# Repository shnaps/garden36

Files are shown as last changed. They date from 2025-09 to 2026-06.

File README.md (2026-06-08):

# garden36 🌱

A 36-key wireless split keyboard with Kailh Choc hotswap switches, nice!nano v2 controllers, and nice!view displays.

<p align="center">
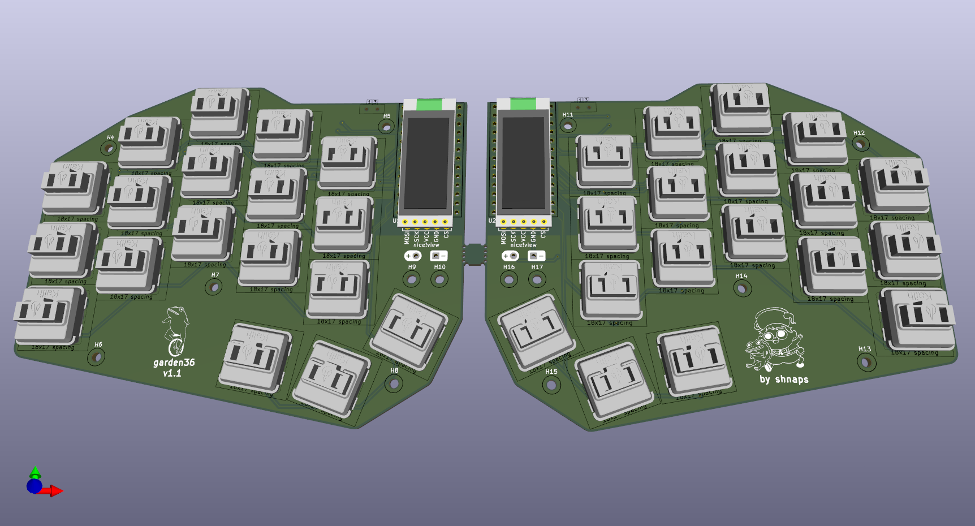
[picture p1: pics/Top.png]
garden36 top view
  
</p>

<p align="center">
  
  
  
  
</p>

---

## Features

- **36 keys** — 3×5 column-stagger + 3 thumb keys per half
- **Wireless** — nRF52840 via nice!nano v2, ZMK firmware
- **Hotswap** — Kailh Choc v1 sockets, swap switches without soldering
- **Display** — nice!view MIP display per half (WPM, layer, battery)
- **Battery** — JST-PH LiPo connector + power switch per half
- **Low profile** — Choc spacing, slim build

---

## Gallery

| Top | Bottom |
|-----|---|
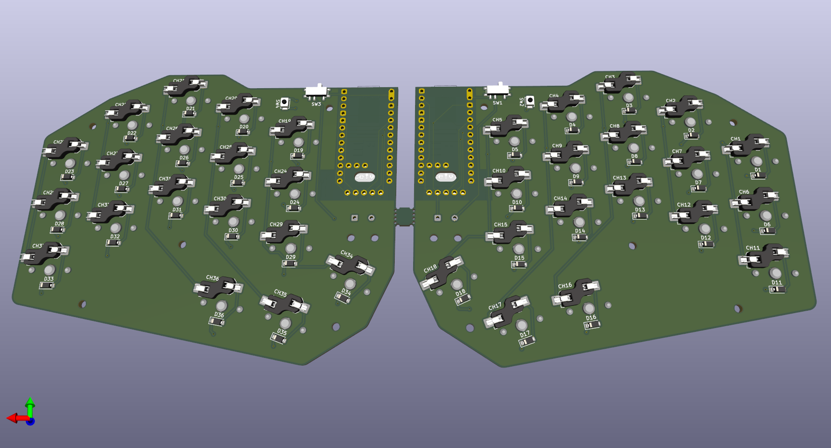
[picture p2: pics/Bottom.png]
bottom
| top |  |

> Photos of the built keyboard coming once V2 is assembled. See `pics/photos/` for updates.

---

## Bill of Materials

Full BOM with source links: [docs/bom.md](docs/bom.md)

| Component | Qty |
|---|-----|
| nice!nano v2 | 2 |
| nice!view | 2 |
| Kailh Choc v1 switch | 36 |
| Kailh hotswap socket CPG135001S30 | 36 |
| 1N4148W diode SOD-123 | 36 |
| MSK12C02-HB power switch | 2 |
| B3U-1000P reset button | 2 |
| JST S2B-PH-SM4-TB battery connector | 2 |
| LiPo battery ~110–300 mAh | 2 |
| M2 standoffs + screws | ~28 |
| Choc keycaps | 36 |

---

## PCB

Gerbers and drill files for JLCPCB/PCBWay are in the [latest release](https://github.com/shnaps/garden36/releases/latest).

DXF and SVG edge cuts for laser-cutting plates: [`exports/`](exports/)

---

## Build Guide

Step-by-step assembly instructions: [docs/buildguide.md](docs/buildguide.md)

---

## Firmware

ZMK config: [github.com/shnaps/zmk-config](https://github.com/shnaps/zmk-config)

Flash via UF2 — double-tap reset on each half to enter bootloader, drag-and-drop `.uf2`. See build guide for details.

---

## Case

A **parametric case generator** lives in [`case-gen/`](case-gen/) — it builds
the case (bottom tray, choc switch plate, controller cover) straight from
`garden36.kicad_pcb`, so it always fits the board. Print files in
`case-gen/out/`. See the [case-gen README](case-gen/README.md) for hardware,
parameters, and the in-progress controller-on-bottom redesign.

Older hand-built STEP files remain in [`case/`](case/).

---

## Design History

- **V1** — initial design, 5-column, wired (see [`v1` branch](https://github.com/shnaps/garden36/tree/v1))
- **V2** (current) — redesigned with wireless, nice!view displays, hotswap

---

## Credits

- [marbastlib](https://github.com/ebastler/marbastlib) by ebastler — Choc switch and controller footprints
- [nice!keyboards](https://nicekeyboards.com) — nice!nano and nice!view hardware
- Split keyboard inspiration: [MRIYA](https://github.com/themaxbang/MRIYA), [temper](https://github.com/raeedcho/temper), [urchin](https://github.com/duckyb/urchin)

---

## License

[MIT](LICENSE) © 2025 Viachaslau Ravinski

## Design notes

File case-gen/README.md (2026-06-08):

# garden36 — parametric case generator

Generates the 3D-printed case directly from `garden36.kicad_pcb`, so the case
always fits the board. Reads the board outline, switch positions (with splay),
mounting holes, and the controller / nice!view / power / reset / battery
locations, then builds each part as a STEP + STL.

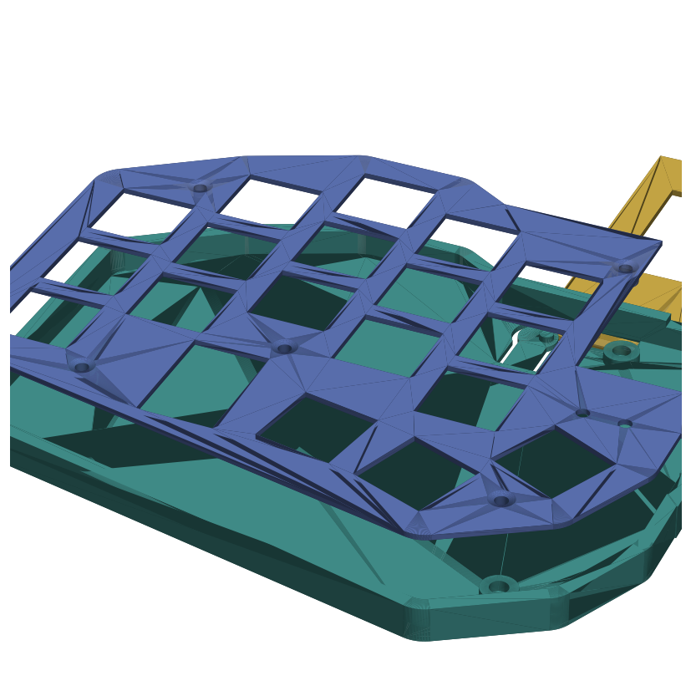
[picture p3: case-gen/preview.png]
exploded preview


> **Status: work in progress.** Geometry is print-tested and iterating. A
> larger redesign is planned — see *Next* below.

## Parts (per half)

| File | What |
|---|---|
| `*_bottom` | tray: floor, perimeter wall, 5 printed standoffs (insert pockets), printed reset flexure, power-switch slot, USB notch |
| `*_top` | choc switch plate (rotated cutouts follow key splay), logo windows, controller opening, screw bosses |
| `*_cover_view` | flat controller cover with nice!view window, floats on the 2 battery standoffs |
| `*_cover_plain` | same cover, solid (display removed) |

Outputs land in `out/stl/` (slicer) and `out/step/` (CAD).

## Hardware (per half)

| Use | Part |
|-----|---|
| 5 case columns | printed standoff + **M2×3×OD3.5 heat-set insert** + **M2×8 countersunk** from plate |
| Controller cover (display) | **M2×10** F-F standoff at each battery hole + **M2×4** screws |
| Controller cover (plain) | **M2×7** F-F standoff instead |

## Run

```bash
# one-time env (build123d needs Python <=3.12)
uv venv --python 3.12 .venv-case
uv pip install --python .venv-case build123d numpy-stl matplotlib

# generate
.venv-case/Scripts/python extract_pcb.py   # PCB -> pcb_data.json
.venv-case/Scripts/python case_gen.py       # -> out/stl, out/step
```

Edit a PCB feature in KiCad → rerun both → the case refits.

## Key parameters (`case_gen.py`)

All in mm, top of file. The ones that matter for fit:

- `UNDER_PCB` — space under the PCB (choc socket clearance + insert seat)
- `ABOVE_PCB` — plate underside above PCB = where the choc switches hold the
  plate. **Tune this to your exact top/bottom gap** (1.6mm plates sit ~1mm proud
  of the 1.2–1.3 clip notch)
- `PLATE_T` — 1.6 (held by screws). Drop to 1.3 if you want choc clips to engage
- `CTRL_STANDOFF` / `DISPLAY_TOP` — controller cover height; must clear the
  nice!view

## Next — controller-on-bottom redesign

Resoldering the nano to the **bottom** of the PCB (the footprints are fully
through-hole / reversible, so no board respin needed). This lets the nice!view
sit low on top instead of stacked on the nano → near-flush top, USB-C notch
moves to the bottom wall, battery moves under the PCB. Case will be regenerated
for that stack once the board is reworked.

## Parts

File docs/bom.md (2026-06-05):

# Bill of Materials — garden36

Per side × 2 = full build. Quantities below are **per keyboard** (both halves).

## Electronics

| Component | Qty | Notes | Source |
|---|-----|---|---|
| nice!nano v2 | 2 | nRF52840 wireless MCU, one per half | [typeractive](https://typeractive.xyz/products/nice-nano) |
| nice!view | 2 | MIP display, one per half | [typeractive](https://typeractive.xyz/products/nice-view) |
| Kailh Choc v1 switch | 36 | Any Choc v1 linear/tactile/clicky | [typeractive](https://typeractive.xyz/collections/switches) |
| Kailh Choc hotswap socket CPG135001S30 | 36 | | [typeractive](https://typeractive.xyz/products/kailh-hotswap-sockets) |
| 1N4148W diode SOD-123 | 36 | One per switch | [LCSC C2290336](https://www.lcsc.com/product-detail/C2290336.html) / AliExpress |
| MSK12C02-HB slide switch | 2 | Power on/off per half | [LCSC C431540](https://www.lcsc.com/product-detail/C431540.html) |
| B3U-1000P tactile reset switch | 2 | One per half | [LCSC C841584](https://www.lcsc.com/product-detail/C841584.html) |
| JST S2B-PH-SM4-TB battery connector | 2 | | [LCSC C295747](https://www.lcsc.com/product-detail/C295747.html) |
| LiPo battery 301230 or similar | 2 | ~100–300 mAh, fits under MCU | AliExpress |
| Mill-Max 315-43-112-41-003000 socket (12-pin) | 4 | For socketing nice!nano (optional but recommended) | [Digikey](https://www.digikey.com) |
| Mill-Max 315-43-105-41-003000 socket (5-pin) | 4 | For socketing nice!view (optional but recommended) | [Digikey](https://www.digikey.com) |

## PCB & Case

| Item | Qty | Notes |
|---|-----|---|
| garden36 PCB | 2 halves | Order via JLCPCB/PCBWay from gerbers in release |
| Top plate | 2 | `case/Only top.step` (FR4 or acrylic, 1.5mm) |
| Bottom plate | 2 | `case/Bottom left.step`, `case/Bottom right.step` |
| M2 × 6mm standoff | ~14 | Exact qty depends on case variant |
| M2 × 4mm screw | ~28 | |
| Choc keycaps | 36 | Low-profile Choc spacing | [typeractive](https://typeractive.xyz/collections/keycaps) |

## Optional

| Item | Notes |
|---|---|
| TRRS cable | If using wired split connection (ZMK supports wireless only, no TRRS needed) |
| USB-C cable | For flashing firmware |

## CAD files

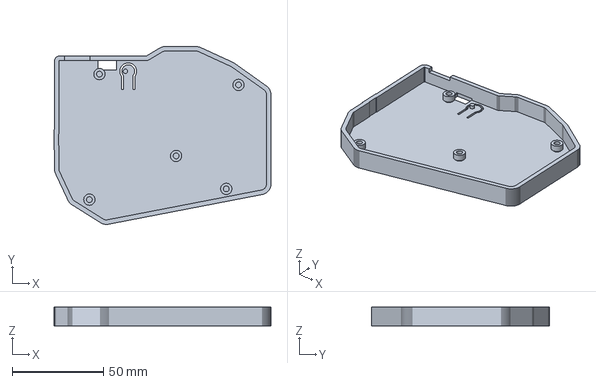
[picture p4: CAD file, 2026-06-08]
case-gen/out/step/right_bottom.step
118.8 x 97.4 x 10.4 mm

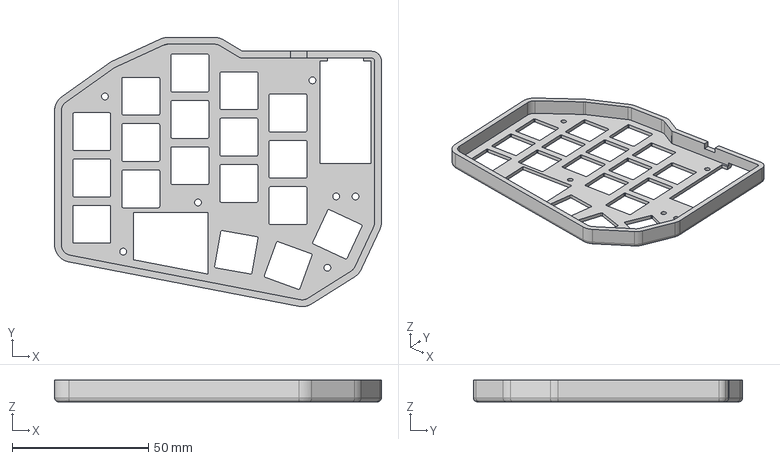
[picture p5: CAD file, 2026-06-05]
case/Untitled.step
120.0 x 98.8 x 8.00 mm

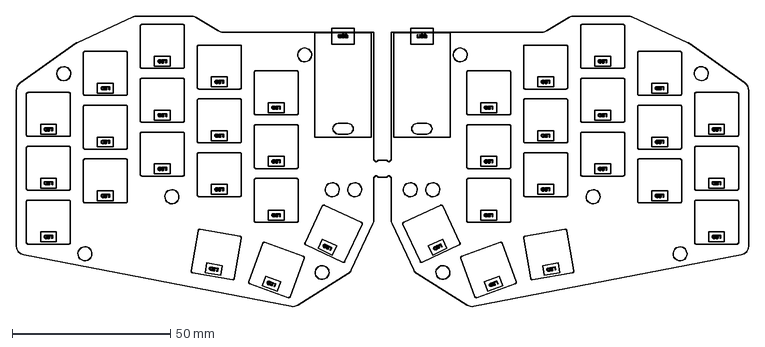
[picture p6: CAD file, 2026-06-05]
exports/garden36-Edge_Cuts.dxf
231.5 x 91.9 mm

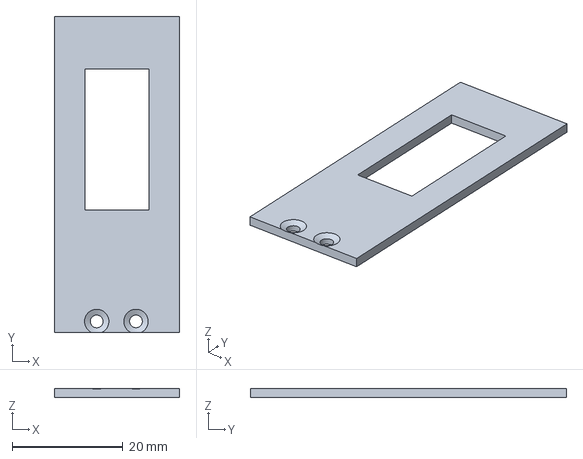
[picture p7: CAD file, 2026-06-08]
case-gen/out/step/right_cover_view.step
22.6 x 57.1 x 1.60 mm

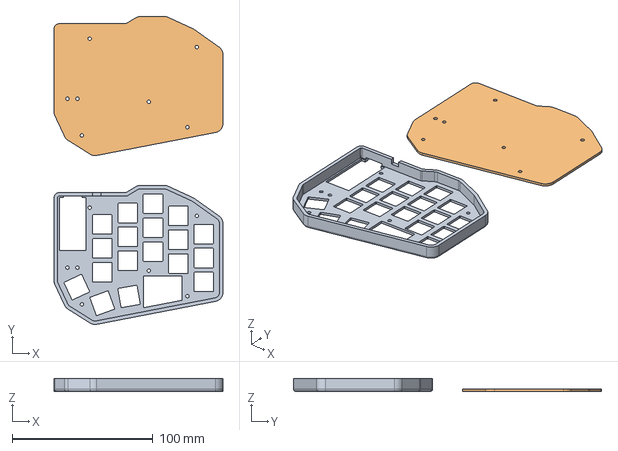
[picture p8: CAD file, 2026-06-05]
case/Left.step
120.0 x 218.8 x 9.00 mm

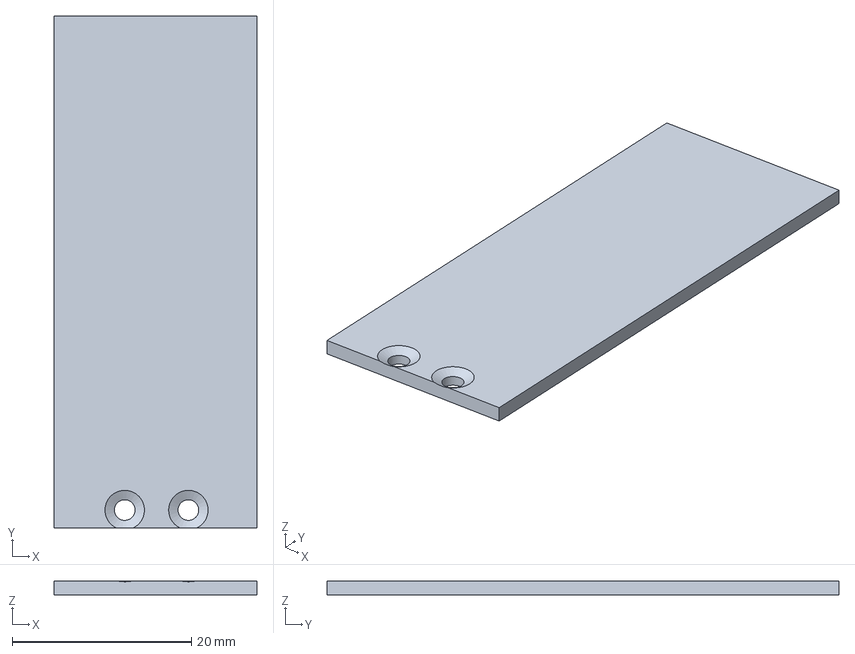
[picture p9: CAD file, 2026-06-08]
case-gen/out/step/left_cover_plain.step
22.6 x 57.1 x 1.60 mm

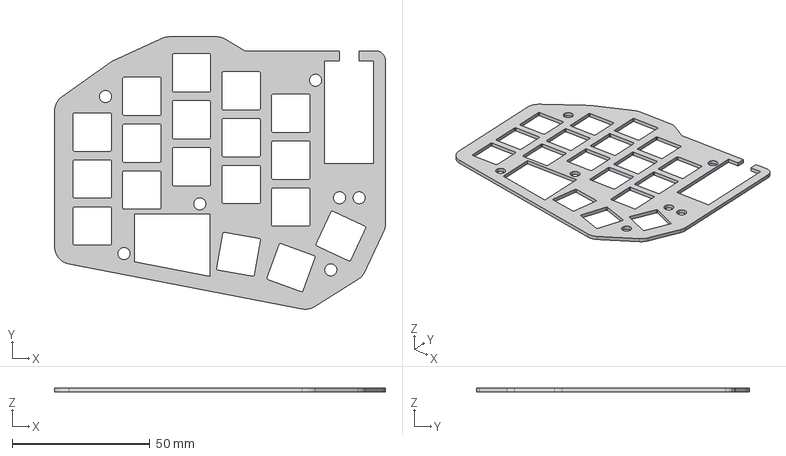
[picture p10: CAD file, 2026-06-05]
case/Only top.step
120.0 x 98.8 x 1.60 mm

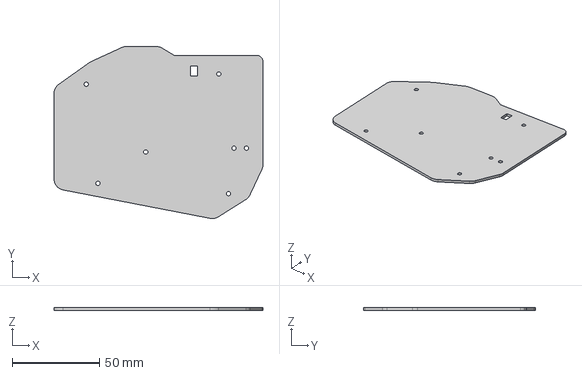
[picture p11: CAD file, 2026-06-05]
case/Bottom right.step
120.0 x 98.8 x 1.60 mm

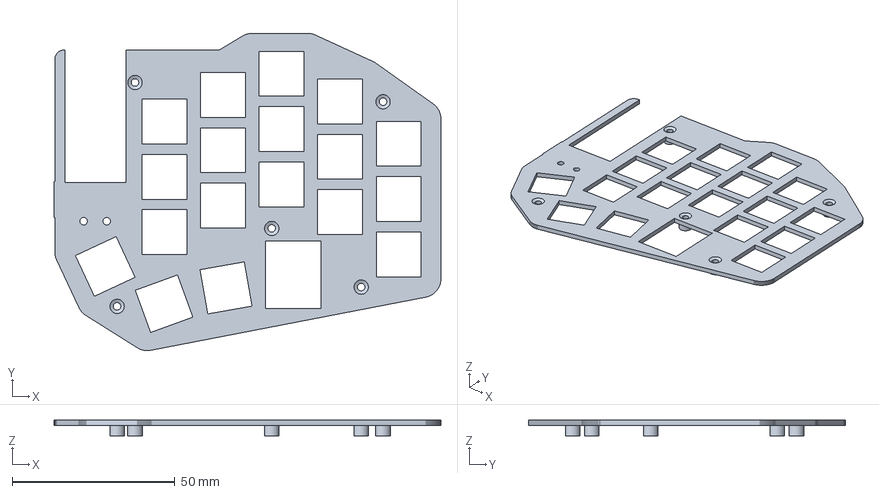
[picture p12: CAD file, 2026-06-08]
case-gen/out/step/right_top.step
118.8 x 97.4 x 4.80 mm

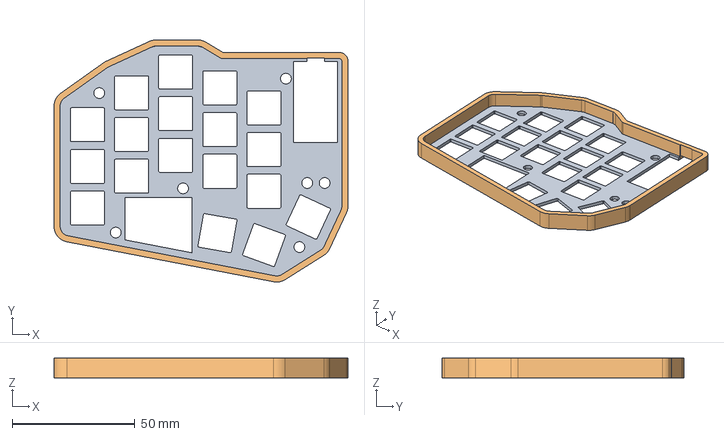
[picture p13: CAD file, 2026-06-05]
case/Rn.step
120.0 x 98.8 x 8.00 mm

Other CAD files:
case-gen/out/step/right_cover_plain.step
case/Bottom left.step
case-gen/out/step/left_top.step
case/Right.step
case-gen/out/step/left_cover_view.step
case-gen/out/step/left_bottom.step
case/Top2.step
case/drawing.FCStd
case-gen/out/stl/left_bottom.stl
case-gen/out/stl/left_cover_plain.stl
case-gen/out/stl/left_cover_view.stl
case-gen/out/stl/left_top.stl
case-gen/out/stl/right_bottom.stl
case-gen/out/stl/right_cover_plain.stl
case-gen/out/stl/right_cover_view.stl
case-gen/out/stl/right_top.stl

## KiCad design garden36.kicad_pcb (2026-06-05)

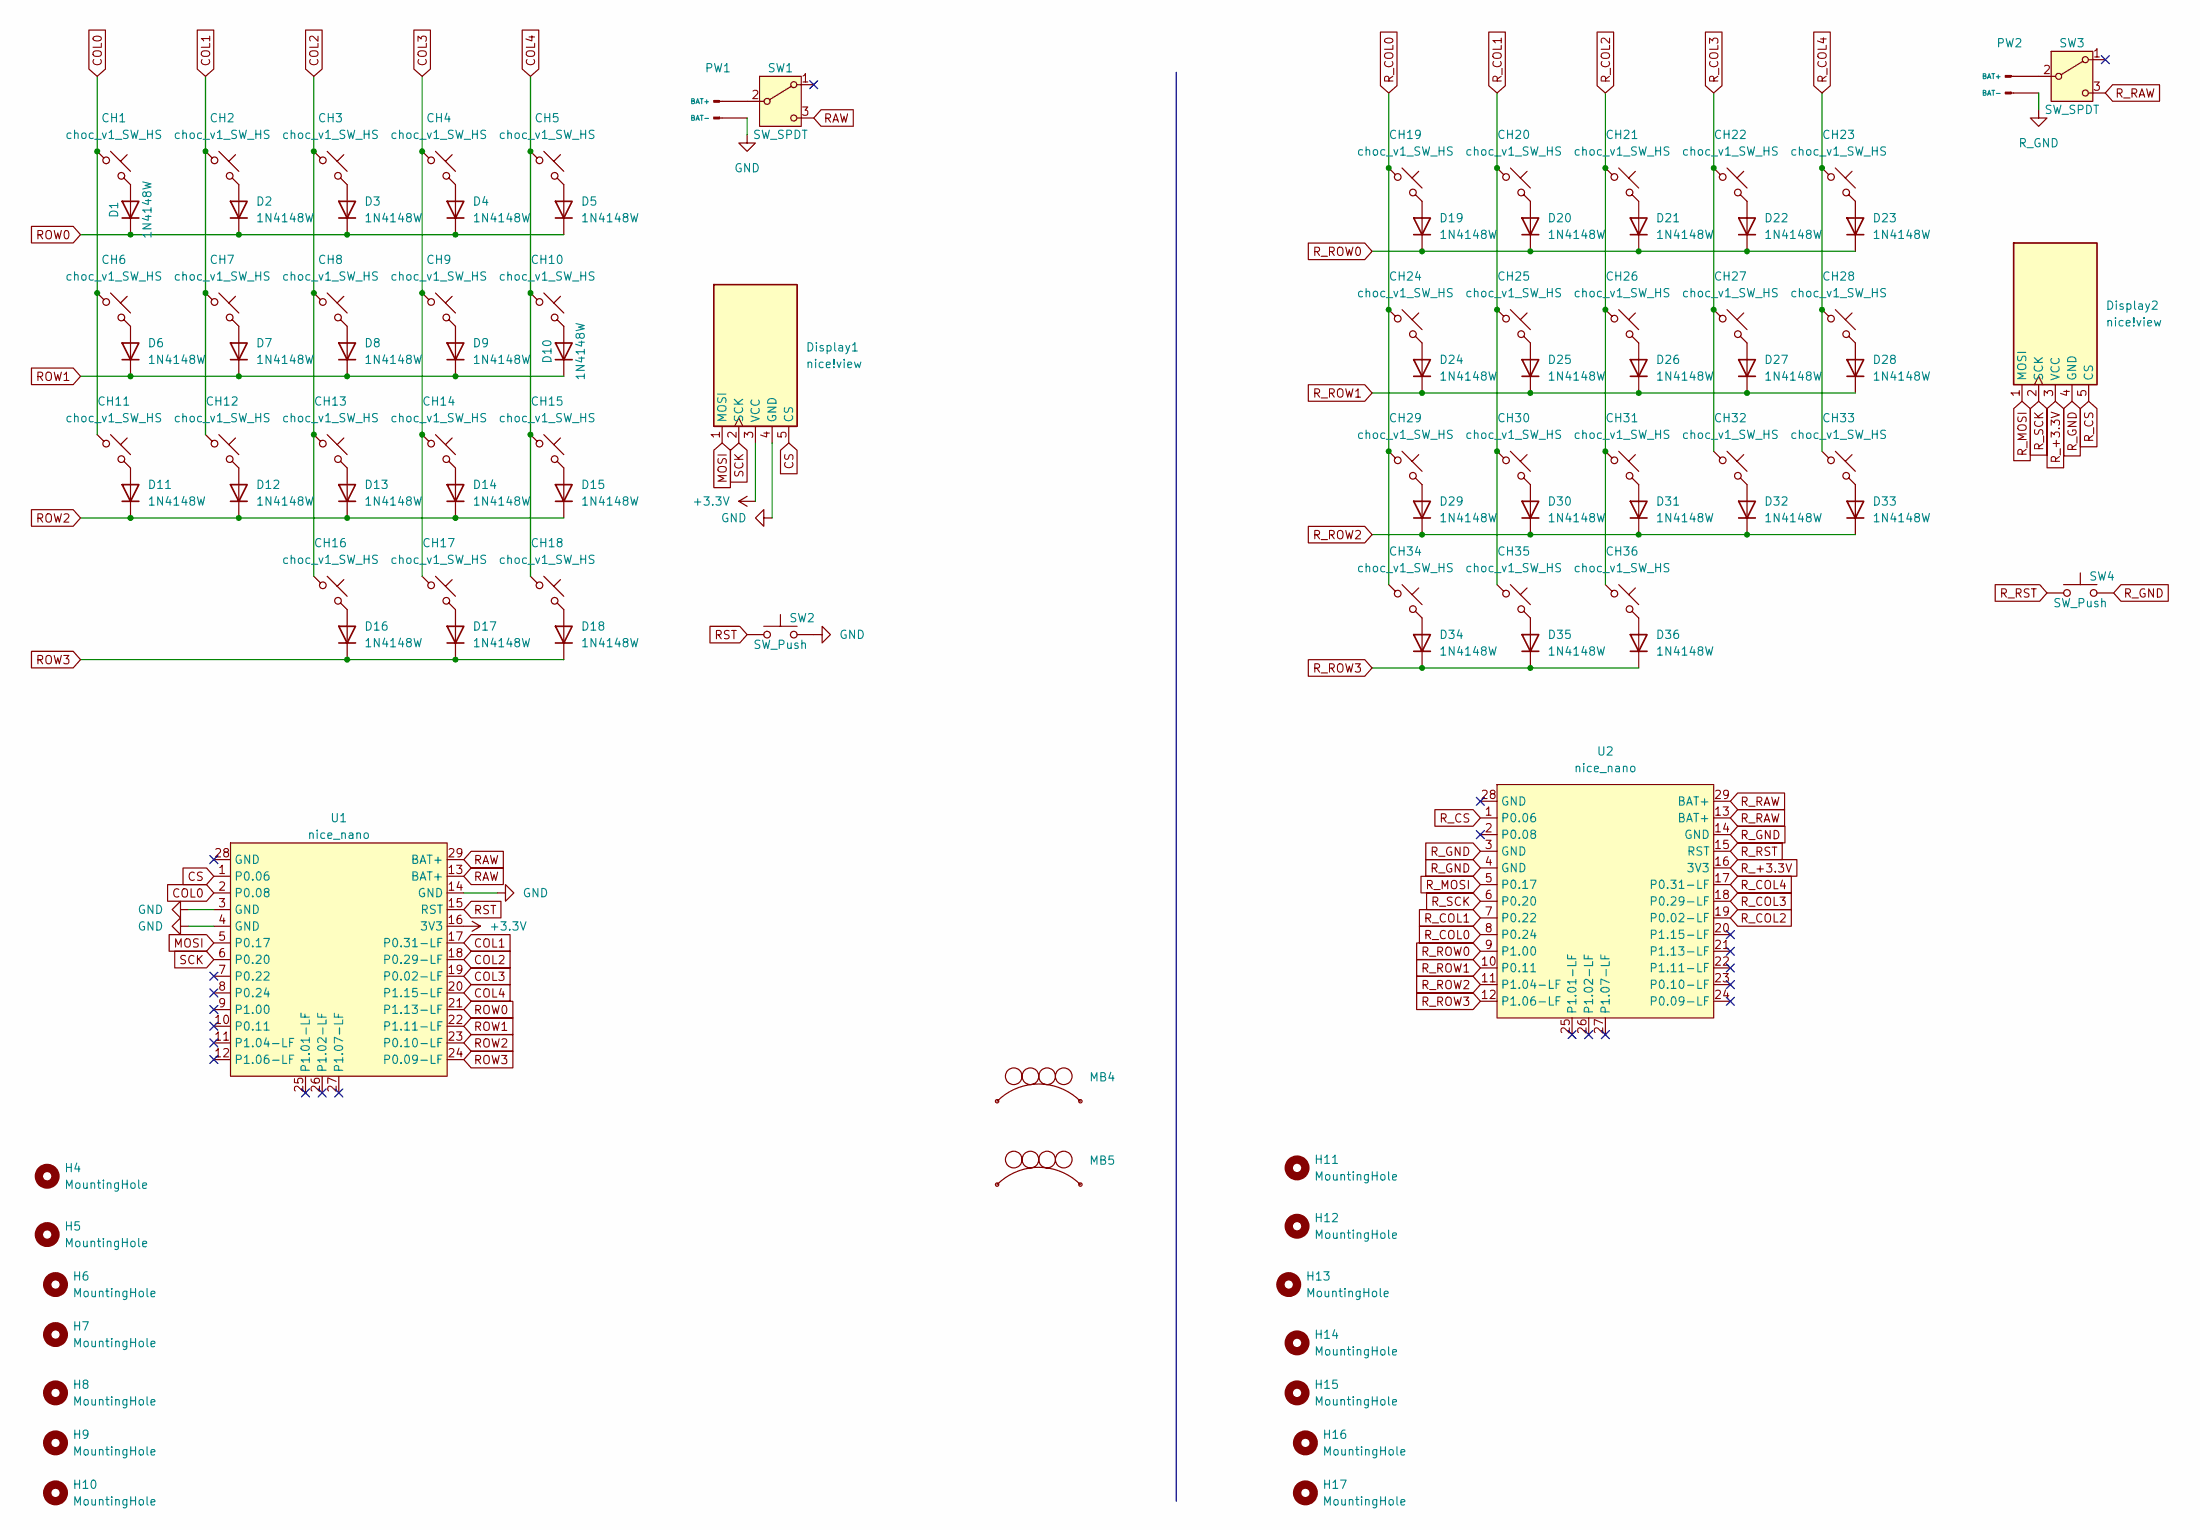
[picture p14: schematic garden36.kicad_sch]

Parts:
CH1, CH2, CH3, CH4, CH5, CH6, CH7, CH8, CH9, CH10, CH11, CH12, CH13, CH14, CH15, CH16, CH17, CH18, CH19, CH20, CH21, CH22, CH23, CH24, CH25, CH26, CH27, CH28, CH29, CH30, CH31, CH32, CH33, CH34, CH35, CH36: choc_v1_SW_HS; SW_choc_v1_HS_CPG135001S30_1u
D1, D2, D3, D4, D5, D6, D7, D8, D9, D10, D11, D12, D13, D14, D15, D16, D17, D18, D19, D20, D21, D22, D23, D24, D25, D26, D27, D28, D29, D30, D31, D32, D33, D34, D35, D36: 1N4148W; D_SOD-123
Display1, Display2: nice!view; nice_view
H4, H5, H6, H7, H8, H9, H10, H11, H12, H13, H14, H15, H16, H17: MountingHole; MountingHole_2.2mm_M2
MB4, MB5: mousebites_1mm
PW1, PW2: Battery
SW1, SW3: SW_SPDT; SW_MSK12C02-HB
SW2, SW4: SW_Push; SW_SPST_B3U-1000P
U1, U2: nice_nano; nice_nano_AH_USBdn

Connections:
+3.3V: Display1.3 (VCC), U1.16 (3V3)
COL0: CH1.1, CH6.1, CH11.1, U1.2 (P0.08)
COL1: CH2.1, CH7.1, CH12.1, U1.17 (P0.31-LF)
COL2: CH3.1, CH8.1, CH13.1, CH16.1, U1.18 (P0.29-LF)
COL3: CH4.1, CH9.1, CH14.1, CH17.1, U1.19 (P0.02-LF)
COL4: CH5.1, CH10.1, CH15.1, CH18.1, U1.20 (P1.15-LF)
CS: Display1.5 (CS), U1.1 (P0.06)
GND: Display1.4 (GND), PW1.2 (BAT-), SW2.2, U1.3 (GND), U1.4 (GND), U1.14 (GND)
MOSI: Display1.1 (MOSI), U1.5 (P0.17)
unnamed: CH1.2, D1.2 (A)
unnamed: CH2.2, D2.2 (A)
unnamed: CH3.2, D3.2 (A)
unnamed: CH4.2, D4.2 (A)
unnamed: CH5.2, D5.2 (A)
unnamed: CH6.2, D6.2 (A)
unnamed: CH7.2, D7.2 (A)
unnamed: CH8.2, D8.2 (A)
unnamed: CH9.2, D9.2 (A)
unnamed: CH10.2, D10.2 (A)
unnamed: CH11.2, D11.2 (A)
unnamed: CH12.2, D12.2 (A)
unnamed: CH13.2, D13.2 (A)
unnamed: CH14.2, D14.2 (A)
unnamed: CH15.2, D15.2 (A)
unnamed: CH16.2, D16.2 (A)
unnamed: CH17.2, D17.2 (A)
unnamed: CH18.2, D18.2 (A)
unnamed: CH19.2, D19.2 (A)
unnamed: CH20.2, D20.2 (A)
unnamed: CH21.2, D21.2 (A)
unnamed: CH22.2, D22.2 (A)
unnamed: CH23.2, D23.2 (A)
unnamed: CH24.2, D24.2 (A)
unnamed: CH25.2, D25.2 (A)
unnamed: CH26.2, D26.2 (A)
unnamed: CH27.2, D27.2 (A)
unnamed: CH28.2, D28.2 (A)
unnamed: CH29.2, D29.2 (A)
unnamed: CH30.2, D30.2 (A)
unnamed: CH31.2, D31.2 (A)
unnamed: CH32.2, D32.2 (A)
unnamed: CH33.2, D33.2 (A)
unnamed: CH34.2, D34.2 (A)
unnamed: CH35.2, D35.2 (A)
unnamed: CH36.2, D36.2 (A)
unnamed: PW1.1 (BAT+), SW1.2 (B)
unnamed: PW2.1 (BAT+), SW3.2 (B)
RAW: SW1.3 (C), U1.13 (BAT+), U1.29 (BAT+)
ROW0: D1.1 (K), D2.1 (K), D3.1 (K), D4.1 (K), D5.1 (K), U1.21 (P1.13-LF)
ROW1: D6.1 (K), D7.1 (K), D8.1 (K), D9.1 (K), D10.1 (K), U1.22 (P1.11-LF)
ROW2: D11.1 (K), D12.1 (K), D13.1 (K), D14.1 (K), D15.1 (K), U1.23 (P0.10-LF)
ROW3: D16.1 (K), D17.1 (K), D18.1 (K), U1.24 (P0.09-LF)
RST: SW2.1, U1.15 (RST)
R_+3.3V: Display2.3 (VCC), U2.16 (3V3)
R_COL0: CH19.1, CH24.1, CH29.1, CH34.1, U2.8 (P0.24)
R_COL1: CH20.1, CH25.1, CH30.1, CH35.1, U2.7 (P0.22)
R_COL2: CH21.1, CH26.1, CH31.1, CH36.1, U2.19 (P0.02-LF)
R_COL3: CH22.1, CH27.1, CH32.1, U2.18 (P0.29-LF)
R_COL4: CH23.1, CH28.1, CH33.1, U2.17 (P0.31-LF)
R_CS: Display2.5 (CS), U2.1 (P0.06)
R_GND: Display2.4 (GND), PW2.2 (BAT-), SW4.2, U2.3 (GND), U2.4 (GND), U2.14 (GND)
R_MOSI: Display2.1 (MOSI), U2.5 (P0.17)
R_RAW: SW3.3 (C), U2.13 (BAT+), U2.29 (BAT+)
R_ROW0: D19.1 (K), D20.1 (K), D21.1 (K), D22.1 (K), D23.1 (K), U2.9 (P1.00)
R_ROW1: D24.1 (K), D25.1 (K), D26.1 (K), D27.1 (K), D28.1 (K), U2.10 (P0.11)
R_ROW2: D29.1 (K), D30.1 (K), D31.1 (K), D32.1 (K), D33.1 (K), U2.11 (P1.04-LF)
R_ROW3: D34.1 (K), D35.1 (K), D36.1 (K), U2.12 (P1.06-LF)
R_RST: SW4.1, U2.15 (RST)
R_SCK: Display2.2 (SCK), U2.6 (P0.20)
SCK: Display1.2 (SCK), U1.6 (P0.20)

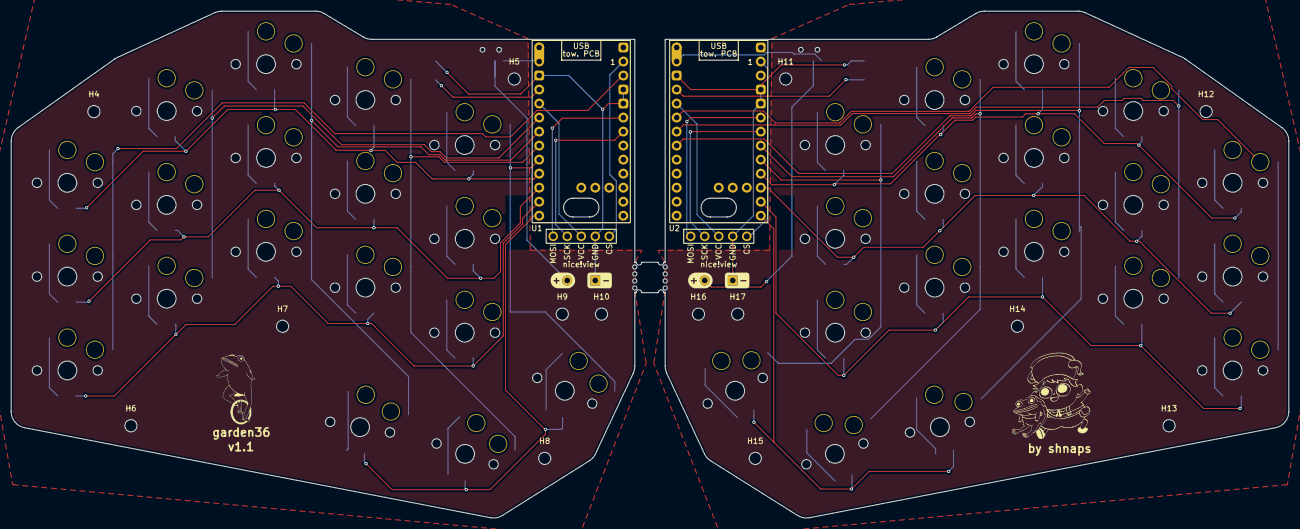
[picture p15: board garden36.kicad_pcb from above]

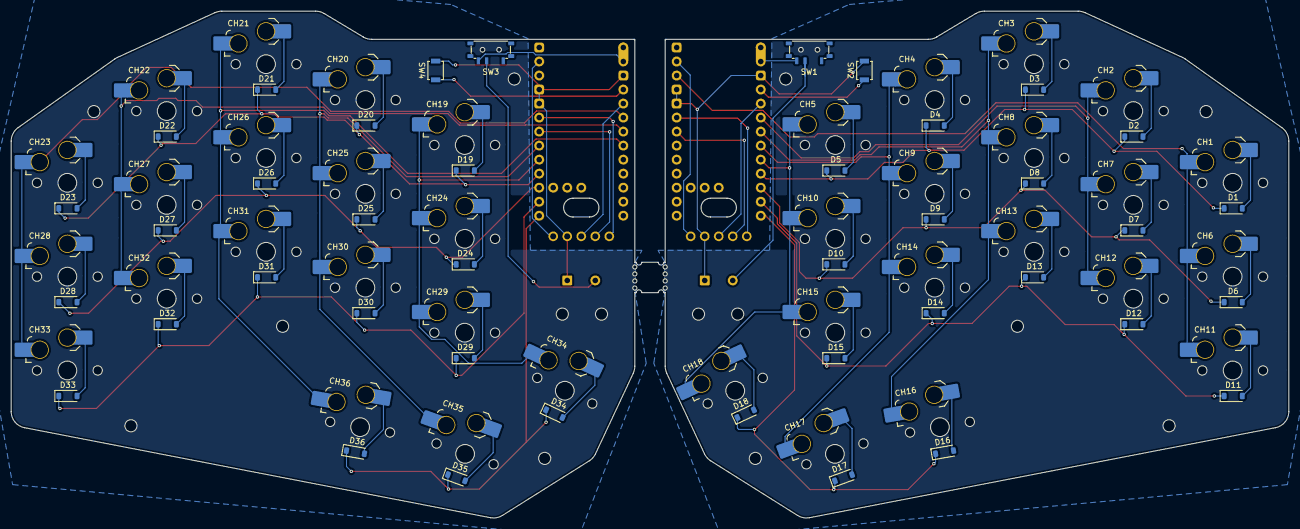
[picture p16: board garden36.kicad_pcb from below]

Board: 2 copper layers, 231.5 x 91.8 mm, 100 parts (76 on the bottom side), 70 nets.

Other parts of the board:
by shnaps: LOGO
garden36: LOGO

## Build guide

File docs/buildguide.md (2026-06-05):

# Build Guide — garden36

> Build both halves in parallel — steps are identical for left and right.

## What you need

- Soldering iron (fine tip, ~320°C) + solder
- Tweezers
- Flux
- USB-C cable
- [Full BOM](bom.md)

---

## 1. Order the PCB

Download gerbers from the [latest release](https://github.com/shnaps/garden36/releases/latest).

JLCPCB settings:
- **Layers:** 2
- **Thickness:** 1.6mm
- **Surface finish:** HASL or ENIG
- **Color:** your choice
- All other settings: default

---

## 2. Solder diodes

1. Tin one pad of each diode footprint.
2. Place 1N4148W **SOD-123** diode with cathode (line) matching the PCB silkscreen mark.
3. Reflow the pre-tinned pad, then solder the other side.
4. Do all 18 diodes per half before moving on.

> Diodes are **surface-mount** on the bottom (B.Cu) side of the PCB.

---

## 3. Solder hotswap sockets

1. Place Kailh CPG135001S30 sockets in the hotswap footprints on the **bottom** side.
2. Press firmly while soldering both pads — sockets must sit flush.

---

## 4. Solder power switch

Solder **MSK12C02-HB** slide switch to the `SW` footprint. Orient per silkscreen.

---

## 5. Solder reset button

Solder **B3U-1000P** tactile switch to the `RST` footprint.

---

## 6. Solder battery connector

Solder **JST S2B-PH-SM4-TB** to the `J1` footprint on the bottom side. Pin 1 = positive (check silkscreen).

---

## 7. Socket the nice!nano

**Recommended: socket it** (Mill-Max 315 sockets) so it's swappable.

1. Insert Mill-Max 12-pin sockets into the PCB from the **top** side.
2. Tack with solder on bottom side.
3. Solder all 24 pins (12 per row).
4. nice!nano mounts **components-side down, USB toward the top edge** of the PCB — this is the "USB facing PCB" (AH) orientation.

To socket permanently without Mill-Max: solder nice!nano directly in the same orientation.

---

## 8. Socket the nice!view

1. Insert 5-pin Mill-Max socket into the `Display` footprint from the top side.
2. Solder from the bottom.
3. nice!view connects via the 5-pin header — plug it in after flashing.

---

## 9. Flash firmware

Before installing the battery:

1. Connect nice!nano via USB-C.
2. Double-tap the reset button — nice!nano enters bootloader (appears as USB drive).
3. Download the `.uf2` from the [ZMK config repo](https://github.com/shnaps/zmk-config).
4. Drag-and-drop `.uf2` onto the drive. Device reboots automatically.
5. Repeat for the other half (left and right have separate firmware files).

---

## 10. Install battery

1. Connect LiPo battery JST-PH plug to `J1`.
2. Verify polarity before connecting — reverse polarity damages the MCU.
3. Route battery cable under the MCU.

---

## 11. Assemble case

1. Attach top plate over switches.
2. Insert standoffs through PCB + plates.
3. Screw bottom plate in place.

STEPs for plates are in `case/`. FreeCAD source: `case/drawing.FCStd`.

---

## 12. Test

- Power on both halves (slide switch).
- Open a text editor — type some keys.
- nice!view should show layer/WPM info.
- Both halves connect wirelessly via ZMK Bluetooth split.

---

## Troubleshooting

| Issue | Fix |
|---|-----|
| Key not registering | Check diode orientation, hotswap socket seating |
| Half not connecting | Re-pair: clear bonds in ZMK, re-flash if needed |
| Display blank | Check nice!view socket pins, reseat display |
| Battery drains fast | Check MSK12C02 is OFF when not in use |

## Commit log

2025-03-04 Garden36 creation
    [garden36.kicad_pcb, garden36.kicad_sch]
2025-03-05 Add .gitignore and ready schema
    [garden36.kicad_pcb, garden36.kicad_sch]
2025-03-06 Move PCB board around
    [garden36.dsn, garden36.kicad_pcb, garden36.kicad_sch]
2025-03-06 Remove .lck files from kicad
2025-03-09 Finished basic layout without any routing
    [garden36.kicad_pcb, garden36.kicad_sch]
2025-03-09 Add v1.1 of buttons and update outline to 0.5mm
    [garden36.kicad_pcb]
2025-03-09 Remove user.1 drawings from kicad
    [garden36.kicad_pcb]
2025-03-10 Finished trace routing for left part
    [garden36.dsn, garden36.kicad_pcb, garden36.kicad_sch]
2025-03-11 Add right half of keyboard
    [garden36.kicad_pcb, garden36.kicad_sch]
2025-03-11 Finished routing for both halfs
    [garden36.kicad_pcb]
2025-03-11 Filled zones for both halfs
    [garden36.kicad_pcb, garden36.kicad_sch]
2025-05-15 V1 ordered
    [garden36.kicad_pcb, garden36.kicad_sch]
2025-09-11 V2 started
    [garden36.kicad_pcb, garden36.kicad_sch]
2025-09-13 Update libraries continue with updates for project
    [garden36.kicad_pcb, garden36.kicad_sch]
2025-09-14 Switches set
    [garden36.kicad_pcb, garden36.kicad_sch]
2025-09-14 Mounting holes for left added
    [garden36.kicad_pcb, garden36.kicad_sch]
2025-09-15 Add mousebites symbol
    [garden36.kicad_pcb]
2025-09-15 Positioning done
    [garden36.kicad_pcb]
2025-09-15 Start adding routes
    [freerouting.dsn, garden36.kicad_pcb, garden36.kicad_sch]
2025-09-16 Start connecting to MCU
    [garden36.kicad_pcb]
2025-09-16 Finish design
    [garden36.kicad_pcb, garden36.kicad_sch]
2025-09-17 V2 ordered
    [garden36.kicad_pcb, temp-freerouting.dsn]
2026-06-05 Add nice!nano 3D model, clean up repo
    - Attach nrf52840.step model to nice!nano footprint (fitted to pads)
    - Add FreeCAD drawing
    - Untrack generated files (fp-info-cache, *.kicad_prl, sch backup)
    - Extend .gitignore: autosaves, locks, exports, editor history
    [drawing.FCStd, garden36.kicad_pcb, temp-freerouting.dsn]
2026-06-05 Add README, build guide, BOM, license, case files
    - README with features, gallery, BOM summary, PCB/firmware/case links
    - docs/buildguide.md — numbered assembly steps (temper-style)
    - docs/bom.md — full BOM with qty and source links
    - LICENSE — MIT, Viachaslau Ravinski
    - case/ — STEP plates + FreeCAD drawing (moved from root)
    - exports/ — edge cuts DXF + SVG (was gitignored, now tracked)
    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
    [Bottom left.step, Bottom right.step, Left.step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]
2026-06-08 Add parametric case generator (case-gen/)
    Generates the 3DP case (bottom tray, choc switch plate, floating
    controller cover) directly from garden36.kicad_pcb so it always fits
    the board. Reads outline, splayed switch positions, mounting holes,
    and controller/display/power/reset/battery locations.
    Per half: bottom + top + cover_view/cover_plain, as STL and STEP.
    Hardware: M2x3 inserts + M2x8 (case columns), M2x7/M2x10 standoffs +
    M2x4 (controller cover).
    Work in progress; controller-on-bottom redesign planned (footprints
    are through-hole/reversible, no board respin needed).
    [left_bottom.step, left_bottom.stl, left_cover_plain.step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]
